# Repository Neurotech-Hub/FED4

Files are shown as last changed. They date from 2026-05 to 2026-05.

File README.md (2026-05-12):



<p align="center">
  FED4 Logo
</p>

<p align="center">
  FED4 Demo
</p>

FED4 (Feeding Experimentation Device) is an open-source device for training mice. The device provides comprehensive control over feeding experiments, environmental monitoring, and data collection. Features:

- Automated pellet dispensing system 
- Three nose-pokes
- Pellet approach sensor
- Multi-colored signal LEDs
- Audio feedback
- Haptic feedback
- Temperature/Humidity monitoring
- Activity monitoring
- Optional Hublink integration for network connectivity

See the Wiki for more information!

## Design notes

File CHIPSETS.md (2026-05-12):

# Specific chipsets used in FED4

| Subsystem | Chip / module | Notes |
|---|---|---|
| Main platform | **ESP32 (ESP32‑S3 family)** | Main MCU (library `architectures=esp32`; code notes ESP32‑S3 specifics) |
| Power / battery | **MAX17048** | LiPo fuel gauge / battery monitor |
| Timekeeping | **DS3231** | Real-time clock (RTC) |
| I/O expansion | **MCP23X17** (MCP23017 family) | GPIO expander (photogates, haptics control, ToF XSHUT, etc.) |
| Environmental sensing | **BME680** | Temperature / humidity / pressure / gas |
| Environmental sensing | **VEML7700** | Ambient light |
| Motion / presence | **STHS34PF80** | Motion (presence) sensor |
| Distance / proximity | **VL53L1X** | Time-of-flight (ToF) distance / proximity |
| Inertial (optional) | **LIS3DH** | 3-axis accelerometer (hardware present; optional in sketches) |
| Magnetic (optional) | **MLX90393** | 3-axis magnetometer (hardware present; optional in sketches) |
| Audio | **MAX98357A** | I2S audio amplifier (speaker output) |
| LEDs | **NeoPixel / WS2812-family** | RGB LEDs (front strip + status pixel) |
| Display | **Sharp Memory Display** | 144×168, SPI, 1-bit monochrome |
| Optional wireless | **Hublink (BLE)** | Radio chipset not specified in this repo |

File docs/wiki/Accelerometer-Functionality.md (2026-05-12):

# FED4 Accelerometer Functionality

The FED4 has a **LIS3DH** accelerometer on the secondary I2C bus (address **0x19**). **It is currently not used** by any built-in FED4 programs; the API is available for custom sketches.

**API**

- **`initializeAccel()`** — init sensor (called from `begin()`). Default: ±2g, 50 Hz, high-resolution (12-bit).
- **`readAccel(x, y, z)`** — read acceleration in **m/s²**, remapped to device axes (x = left/right, y = forward/back, z = up/down).
- **`getAccelEvent(&event)`** — raw chip axes via `sensors_event_t`.
- **`setAccelRange(...)`**, **`setAccelDataRate(...)`**, **`setAccelPerformanceMode(...)`** — configure range (±2/4/8/16 g), rate (1–400 Hz), and mode (low-power / normal / high-res).
- **`accelDataReady()`** — `true` when new data is available.

See [FED4_Accel.cpp](https://github.com/KravitzLabDevices/FED4/blob/main/src/FED4_Accel.cpp). Example: [FED4-Accel-Test](https://github.com/KravitzLabDevices/FED4/tree/main/examples/3_Troubleshooting/HardwareExamples/FED4-Accel-Test).

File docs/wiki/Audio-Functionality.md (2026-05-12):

# FED4 Audio Functionality

The FED4 uses an **I2S-driven speaker** (MAX98357A). Audio is initialized in `begin()`.

**Tones and beeps**

- **`playTone(frequency, duration_ms, amplitude)`** — single tone (e.g. `playTone(500, 200, 0.25)`).
- **`lowBeep()`** — 500 Hz, 200 ms. **`highBeep()`** — 1000 Hz. **`higherBeep()`** — 2000 Hz.
- **`click()`** — short click (quick feedback).
- **`bopBeep()`** — two-tone beep (1000 Hz → 1600 Hz).

**Jingles**

- **`playStartup()`** — startup melody. **`resetJingle()`** — power-cycle jingle. **`menuJingle()`** — menu arpeggio.

**"Super Mario"-style sound effects (tone synthesis)**

- **`marioCoin()`** — coin pickup sound (approx).
- **`marioJump()`** — jump sound (approx).
- **`marioPipe()`** — pipe/travel “bloop” (approx).
- **`marioFireball()`** — fireball shot sound (approx).
- **`marioMushroom()`** — power-up sound (approx).

**Other**

- **`soundSweep(startFreq, endFreq, duration_ms)`** — frequency sweep. **`noise(duration_ms, amplitude)`** — white noise.
- **`silence()`** / **`unsilence()`** — mute audio (persists across reboots). **`enableAmp(bool)`** — amp on/off. **`resetSpeaker()`** — reinit I2S.

See [FED4_Audio.cpp](https://github.com/KravitzLabDevices/FED4/blob/main/src/FED4_Audio.cpp).

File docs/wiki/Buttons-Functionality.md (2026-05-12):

# FED4 Buttons Functionality

The FED4 has **three user buttons** (GPIO **BUTTON_1** = 40, **BUTTON_2** = 39, **BUTTON_3** = 14), arranged bottom / middle / top. They use internal pull-down and can **wake the device** from light sleep. There is **no general-purpose “button pressed” API** for sketches; the library assigns fixed behaviors.

**Default behavior (on wake)**

- **`checkButton1()`** — **Button 1 (bottom):** Hold ~1 s → test pellet dispense (`feed()`), `bopBeep()`.
- **`checkButton2()`** — **Button 2 (middle):** Hold ~1 s → **device reset** (red wipe, `resetJingle()`, `esp_restart()`).
- **`checkButton3()`** — **Button 3 (top):** Hold **500 ms** → **audio toggle** (`silence` / `unsilence`), plus `click()`. Hold **1500 ms** → **menu** (`menu()`), `hapticDoubleBuzz()`.

These are run from **`wakeUp()`** after a **button** wake (not touch). Poll with **`digitalRead(BUTTON_1)`** etc. (HIGH = pressed) if you need raw state elsewhere (e.g. menu, dispense loop).

See [FED4_Buttons.cpp](https://github.com/KravitzLabDevices/FED4/blob/main/src/FED4_Buttons.cpp), [FED4_Pins.h](https://github.com/KravitzLabDevices/FED4/blob/main/src/FED4_Pins.h).

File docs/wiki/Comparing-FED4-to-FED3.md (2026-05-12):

# FED4 vs FED3 (Quick Comparison)

This page summarizes high‑level differences using the **FED4 README** and the **FED3 specifications/wiki**. Where FED4 specs are not published, the table notes “not listed.”

## At a glance

| Category | FED4 | FED3 |
|---|---|---|
| **Core purpose** | Feeding experimentation device; integrated environmental monitoring and data logging | Feeding experimentation device |
| **Nose‑pokes** | Three | Three (per FED3 wiki) |
| **Pellet dispenser** | Updated design; **dispensing is greatly improved vs FED3** | Legacy FED3 dispenser |
| **Wireless / cloud** | Optional **Hublink** (BLE → gateway → hublink.cloud), auto‑configured via `meta.json` | Not listed in FED3 specs/wiki |
| **Screen** | Sharp Memory Display, 144×168 (from FED4 code) | Sharp Memory Display (FED3 wiki) |
| **Battery** | Not listed in FED4 README | 3.7 V 4400 mAh (FED3 wiki) |
| **Weight** | Not listed in FED4 README | 295 g (FED3 wiki) |
| **Dimensions** | Not listed in FED4 README | 135×85×86 mm (FED3 wiki) |
| **Processor** | Not listed in FED4 README | Feather M0 Adalogger (FED3 wiki) |

## FED4 highlights (from FED4 README)

| Area | FED4 highlights |
|---|---|
| **Sensors** | BME680 (temp/humidity/pressure/gas), VEML7700 (ambient light), VL53L1X (ToF), STHS34PF80 (motion), DS3231 RTC, plus LIS3DH accel + MLX90393 magnetometer (hardware present; currently unused in default programs) |
| **Outputs** | Multicolor nose‑poke LEDs, audio, haptic, SD logging |
| **Wireless** | Optional Hublink; enable with `fed.useHublink = true` and it syncs automatically in `run()` |

## FED3 specs (from FED3 wiki)

| Spec | FED3 |
|---|---|
| **Weight** | 295 g |
| **Dimensions** | 135×85×86 mm |
| **Processor** | Feather M0 Adalogger |
| **Screen** | Sharp Memory Display |
| **Battery** | 3.7 V 4400 mAh (~7 days continuous) |
| **Pellets** | 20 mg precision pellets (TestDiet, Bio‑Serv, etc.) |

## Sources

- FED4 README: https://github.com/KravitzLabDevices/FED4  
- FED3 specifications (wiki): https://github.com/KravitzLabDevices/FED3/wiki/FED3-Specifications  
- FED3 library: https://github.com/KravitzLabDevices/FED3_library

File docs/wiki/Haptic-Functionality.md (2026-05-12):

# FED4 Haptic Functionality

The FED4 drives a **haptic motor** via the MCP expander (pin **EXP_HAPTIC**). Used for vibration feedback on pokes, buttons, and events.

**Functions**

- **`hapticBuzz(duration)`** — single buzz (default 100 ms).
- **`hapticDoubleBuzz(duration)`** — two buzzes (default 25 ms each).
- **`hapticTripleBuzz(duration)`** — three buzzes (default 5 ms base; on/off = duration×10).
- **`hapticRumble(duration_ms)`** — low-frequency PWM rumble (default 300 ms, 50 Hz).

Durations are in milliseconds unless noted. See [FED4_Haptic.cpp](https://github.com/KravitzLabDevices/FED4/blob/main/src/FED4_Haptic.cpp).

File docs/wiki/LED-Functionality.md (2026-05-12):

# FED4 LED Functionality

The FED4 has **two LED systems**: a **front strip** of 8 NeoPixels around the nose-pokes, and a **single status NeoPixel**.

**Front strip (poke lights)**

- **`leftLight("red")`**, **`centerLight("green")`**, **`rightLight("blue")`** — light left/center/right poke; optional brightness: `leftLight("red", 100)`.
- **`setStripPixel(i, "green")`** — individual strip LED.
- **`colorWipe("white", 10)`**, **`stripRainbow(50, 1)`** — animations; **`lightsOff()`** — clear strip.

**Status pixel**

- **`redPix(5)`**, **`greenPix(5)`**, **`bluePix(5)`**, **`noPix()`**, etc.

**Colors:** `"red"`, `"green"`, `"blue"`, `"yellow"`, `"purple"`, `"cyan"`, `"orange"`, `"white"`.

See [FED4_LEDs.cpp](https://github.com/KravitzLabDevices/FED4/blob/main/src/FED4_LEDs.cpp).

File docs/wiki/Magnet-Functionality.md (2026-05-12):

# FED4 Magnet (Magnetometer) Functionality

The FED4 has an **MLX90393** magnetometer on the secondary I2C bus (address **0x0C**). **It is currently not used** by any built-in FED4 programs; the API is available for custom sketches.

**API**

- **`initializeMagnet()`** — init sensor (called from `begin()`). Uses **`configureMagnet()`** with default gain (5×).
- **`readMagnetData(x, y, z)`** — read magnetic field (µT) into `float` refs. Returns `true` on success.
- **`getMagnetEvent(&event)`** — raw data via `sensors_event_t`.
- **`setMagnetGain(...)`** / **`getMagnetGain()`** — configure or read gain (e.g. `MLX90393_GAIN_5X`).
- **`configureMagnet(gain)`** — set gain, resolution, oversampling, and filter (default 5× gain).

See [FED4_Magnet.cpp](https://github.com/KravitzLabDevices/FED4/blob/main/src/FED4_Magnet.cpp). Hardware: [Adafruit MLX90393](https://www.adafruit.com/product/4022), [Adafruit library](https://github.com/adafruit/Adafruit_MLX90393_Library).

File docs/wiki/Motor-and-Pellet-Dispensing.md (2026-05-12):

# FED4 Motor and Pellet Dispensing

The FED4 drives a **stepper motor** to rotate a hopper and dispense pellets. The **dispenser is greatly improved over FED3**, with better jam handling, pellet-in-well detection, optional drop sensor, and retrieval/poke logging.

**Motor**

- **Stepper:** 4-phase, 512 steps/rev. Pins **MOTOR_PIN_1–4** (46, 37, 21, 38); **MOTOR_SPEED** = 24. **Battery required** for motor operation.
- **`initializeMotor()`** — configure pins, set speed (called from `begin()`).
- **`releaseMotor()`** — coil pins LOW to save power between moves.
- **`motorTurns`** — counts small steps during dispense; ~**25** ≈ one pellet position, ~**1000** ≈ one hopper rotation. Logged (as `motorTurns/25`) on **PelletTaken** etc.

**Dispensing and feeding**

- **`feed()`** — full sequence: **`initFeeding()`** → **`dispense()`** → **`handlePelletSettling()`** → **`handlePelletInWell()`** → **`finishFeeding()`**.
- **`dispense()`** — steps motor (`stepper.step(-10)`) until **`checkForPellet()`** (well) or **`didPelletDrop()`** (optional drop sensor). Every 25 steps, **`releaseMotor()`** + 1 s delay. **`handleJams()`** runs each iteration.
- **`checkForPellet()`** — pellet in well (photogate **EXP_PHOTOGATE_1**). **`didPelletDrop()`** — pellet dropped (optional **EXP_PHOTOGATE_4**); **`initializeDropSensor()`** probes for drop sensor at init.
- **`handlePelletSettling()`** — wait up to **500 ms** for pellet in well; **`dispenseError`** = true if not seen. Then **`handlePelletInWell()`** polls until pellet taken or **20 s** timeout (retrieval time, pokes, etc.).

**Jam handling**

- **`minorJamClear()`** — 200 steps, 1 s pause. **`majorJamClear()`** — 1000 steps. **`vibrateJamClear()`** — short back‑and‑forth wobble. Used at **100** and **200** motorTurns during dispense.
- **`jammed()`** — after **2000** motorTurns without dispense: **DispenseError** on display, **`logData("DispenseError")`**, motor off, then sleep loop; **Button 2** reset to recover.

**Relevant members:** **`pelletCount`**, **`pelletPresent`**, **`pelletDropped`**, **`pelletReady`**, **`dispenseError`**, **`retrievalTime`**, **`pelletDropTime`**, **`pelletWellTime`**, **`blockPelletCount`** / **`blockPokeCount`**.

See [FED4_Motor.cpp](https://github.com/KravitzLabDevices/FED4/blob/main/src/FED4_Motor.cpp), [FED4_Feed.cpp](https://github.com/KravitzLabDevices/FED4/blob/main/src/FED4_Feed.cpp), [FED4_Pins.h](https://github.com/KravitzLabDevices/FED4/blob/main/src/FED4_Pins.h).

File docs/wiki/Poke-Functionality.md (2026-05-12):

# FED4 Poke (Nose-Poke) Functionality

The FED4 has **three nose-pokes** (left, center, right) detected by **ESP32 capacitive touch** pads (see [FED4_Pins.h](https://github.com/KravitzLabDevices/FED4/blob/main/src/FED4_Pins.h)). **Touch wakes** the device from light sleep. After `run()` returns, check `leftTouch`, `centerTouch`, or `rightTouch`; then `logData("Left")` (etc.), `feed()`, and light/sound as needed. Counters: `leftCount`, `centerCount`, `rightCount`; hold duration: `pokeDuration` (ms). Calibration is automatic at startup and periodically; sensitivity can differ on USB vs battery.

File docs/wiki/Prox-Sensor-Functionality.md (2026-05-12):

# FED4 Prox (Proximity) Sensor Functionality

The FED4 uses a **VL53L1X time-of-flight (ToF)** distance sensor on the primary I2C bus (XSHUT on MCP pin 1). Measures approach distance to the nose port.

**API**

- **`initializeToF()`** — init ToF sensor (called from `begin()`). Returns `true` on success.
- **`prox()`** — take a single distance reading. Returns **distance in mm** (0–150), or **`-1`** on error/timeout.

**Details**

- Raw reading is offset by a **20 mm calibration** (configurable in code). Values &lt; 0 are clamped to 0; &gt; 150 mm are capped at 150.
- Used for approach detection (e.g. Pavlovian_Prox) and to exercise the primary I2C bus before secondary use (e.g. in `pollSensors()`).

See [FED4_Prox.cpp](https://github.com/KravitzLabDevices/FED4/blob/main/src/FED4_Prox.cpp). Hardware: [SparkFun VL53L1X](https://www.sparkfun.com/products/14722), [SparkFun Arduino library](https://github.com/sparkfun/SparkFun_VL53L1X_Arduino_Library).

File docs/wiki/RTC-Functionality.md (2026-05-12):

# FED4 RTC (Real-Time Clock) Functionality

The FED4 uses a **DS3231 RTC** on the secondary I2C bus to keep accurate time across power cycles. Time is used for **logs, display, and scheduling**.

**Initialization and auto-update**

- **`initializeRTC()`** — starts the DS3231 and loads time into the internal clock. On **new compilation**, the RTC is updated to the build time.
- **Compilation detection** — a stored compile timestamp in Preferences triggers **`updateRTC()`** only when firmware changes.

**Key API**

- **`now()`** — returns `DateTime` from the RTC.
- **`updateTime()`** — updates `currentHour`, `currentMinute`, `currentSecond`, `unixtime`.
- **`adjustRTC(timestamp)`** — sets RTC from a Unix timestamp (used by Hublink time sync).

**Logging**

- **`ElapsedSeconds`** in the SD log is **millis-based**, rounded to **0.001 s** (1 ms resolution).

**Manual set**

- **`menuRTC()`** — interactive RTC setting in the FED4 menu.

See [FED4_RTC.cpp](https://github.com/KravitzLabDevices/FED4/blob/main/src/FED4_RTC.cpp), [RTClib](https://github.com/adafruit/RTClib).

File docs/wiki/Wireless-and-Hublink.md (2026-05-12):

# FED4 Wireless Capabilities and Hublink

The FED4 supports **wireless connectivity** via **Hublink**, which uses **BLE** to connect nodes (FED4) to a gateway, and the gateway to **[hublink.cloud](https://hublink.cloud)** for time sync, file uploads, and alerts. FED4 is **automatically configured for hublink.cloud** through the **`meta.json`** file on the SD card—no Hublink-specific code is required beyond enabling it.

**Automatic configuration (meta.json)**

- The **`meta.json`** schema is **compatible with hublink.cloud**. A **`hublink`** section configures BLE advertising and upload behavior:
  - **`advertise`** — BLE advertising name (e.g. `"FED4"`).
  - **`advertise_every`** — seconds between advertising periods (e.g. 300).
  - **`advertise_for`** — duration of each advertising period in seconds (e.g. 30).
  - **`upload_path`**, **`append_path`** — where files go in cloud storage (e.g. `/FED`, `subject:id`).
  - **`disable`** — set `true` to turn Hublink off.
- **`subject`**, **`device`**, etc. in **`meta.json`** are used for metadata and paths. The same file drives both FED4 metadata and Hublink; **one config, automatically applied** when Hublink is enabled.

**Enabling Hublink**

- Set **`fed.useHublink = true`** before **`fed.begin(...)`**. **`begin()`** then calls **`initializeHublink()`** (reads **`meta.json`**, starts Hublink). **`run()`** calls **`syncHublink()`** before sleep—**sync is automatic** each wake cycle.
- **`initializeHublink()`** — init Hublink (uses **SD_CS** pin); registers **`onHublinkTimestampReceived`** for RTC updates.
- **`syncHublink()`** — sets battery level, low-battery alerts, and runs **`hublink.sync()`** (advertise/connect, upload files, receive time).

**What runs automatically**

- **RTC time sync** — timestamps from Hublink update the RTC via **`adjustRTC()`**.
- **Low-battery alerts** — battery under 20% triggers **`hublink.setAlert("Low Battery!")`** before sync.
- **File uploads** — log files (and **`meta.json`**) are uploaded according to **`upload_path`** / **`append_path`** when the gateway is in range.

**Optional exclusion**

- **`#define FED4_EXCLUDE_HUBLINK`** before **`#include <FED4.h>`** removes Hublink from the build to save code size.

**Requirements:** Hublink library, SD card with **`meta.json`**, gateway in range for BLE, and internet for the gateway → hublink.cloud.

See [FED4_Hublink.cpp](https://github.com/KravitzLabDevices/FED4/blob/main/src/FED4_Hublink.cpp), [Hublink examples](https://github.com/KravitzLabDevices/FED4/tree/main/examples/4_Hublink), [meta.json example](https://github.com/KravitzLabDevices/FED4/blob/main/extras/meta.json_examples/meta.json). Full config and cloud usage: **[hublink.cloud/docs](https://hublink.cloud/docs)**.

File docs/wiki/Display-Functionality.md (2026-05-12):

# FED4 Display (Screen) Functionality

The FED4 uses a **Sharp Memory Display** (SPI, **DISPLAY_CS** = 17), **144×168** pixels, 1-bit (black/white). The FED4 class extends **Adafruit_GFX**, so you can use standard GFX calls (`drawPixel`, `fillRect`, `print`, `drawLine`, etc.) plus FED4-specific helpers.

**Initialization and refresh**

- **`initializeDisplay()`** — init display, allocate buffer, clear (called from `begin()`).
- **`updateDisplay()`** — redraw status (task, mouse ID, env, battery, SD, counters, indicators, date/time). Called from `run()` and elsewhere.
- **`refresh()`** — push the backing buffer to the display. Call after drawing.
- **`clearDisplay()`** — clear buffer (white) and refresh.

**Status helpers (used by `updateDisplay`)**

- **`displayTask()`**, **`displayMouseId()`**, **`displayEnvironmental()`**, **`displayBattery()`**, **`displaySDCardStatus()`**, **`displayCounters()`**, **`displayIndicators()`**, **`displayDateTime()`** — status layout.
- **`displayActivityMonitor()`** / **`displayActivityCounters()`** — when program is ActivityMonitor.
- **`displayInitStatus(msg)`** — show init message during `begin()`.
- **`displayLowBatteryWarning()`** — low-battery full-screen message.

**Constants:** `DISPLAY_WIDTH` = 144, `DISPLAY_HEIGHT` = 168; **`DISPLAY_BLACK`**, **`DISPLAY_WHITE`**, **`DISPLAY_INVERSE`**, **`DISPLAY_NORMAL`**.

See [FED4_Display.cpp](https://github.com/KravitzLabDevices/FED4/blob/main/src/FED4_Display.cpp), [FED4.h](https://github.com/KravitzLabDevices/FED4/blob/main/src/FED4.h). [Adafruit Sharp Memory Display](https://learn.adafruit.com/adafruit-sharp-memory-display-breakout), [Adafruit_GFX](https://github.com/adafruit/Adafruit-GFX-Library).

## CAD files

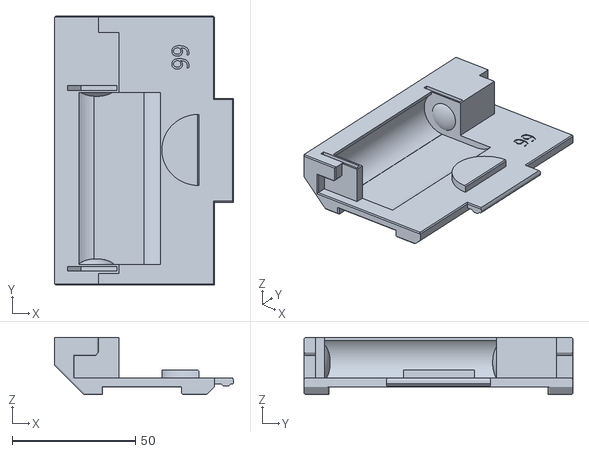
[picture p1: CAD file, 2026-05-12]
extras/3D_designs/FED4_010126_Base_chamfer.stl
72.7 x 109.1 x 23.2

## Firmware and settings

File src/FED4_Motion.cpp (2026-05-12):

#include "FED4.h"

bool FED4::initializeMotion()
{
    // Check if motion sensor should be used
    if (!useMotionSensor) {
        motionSensorInitialized = false;
        motionPercentage = NAN;
        return true; // Return true to indicate "successful" initialization (skipped)
    }
    
    // Reset flag at start of initialization
    motionSensorInitialized = false;
    
    // Test I2C connectivity
#if FED4_BOARD_VERSION == 163
    Wire.beginTransmission(0x5A); // STHS34PF80 default address
    byte error = Wire.endTransmission();
#else
    I2C_2.beginTransmission(0x5A); // STHS34PF80 default address
    byte error = I2C_2.endTransmission();
#endif
    
    if (error != 0) {
        return false;
    }
    
    // Initialize with Adafruit library
#if FED4_BOARD_VERSION == 163
    if (!motionSensor.begin(0x5A, &Wire)) {
#else
    if (!motionSensor.begin(0x5A, &I2C_2)) {
#endif
        return false;
    }
    
    // Set low-pass filter 
    if (!motionSensor.setMotionLowPassFilter(STHS34PF80_LPF_ODR_DIV_50)) {
        return false;
    }
    
    // Set sensitivity to high but not maximum (can cause instability)
    // Range: -128 (ultra sensitive) to 127 (minimum sensitivity)
    if (!motionSensor.setSensitivity(-64)) {
        return false;
    }
    
    // // Use moderate averaging for better stability (default is 32)
    // // Using 8 for good balance between speed and stability
    // if (!motionSensor.setObjAveraging(STHS34PF80_AVG_TMOS_8)) {
    //     return false;
    // }
    
    // Set to 30Hz - maximum rate for motion detection
    // Motion detection REQUIRES continuous operation to maintain baseline
    if (!motionSensor.setOutputDataRate(STHS34PF80_ODR_30_HZ)) {
        return false;
    }

    // Verify sensor is working by reading temperature
    int16_t motionValue1 = motionSensor.readMotion();
    bool motionFlag1 = motionSensor.isMotion();
    
    Serial.println("Motion sensor initialized at 30Hz!");

    // Set flag to prevent unnecessary reinitialization
    motionSensorInitialized = true;
    
    return true;
}

bool FED4::motion()
{
    // Check if motion sensor should be used
    if (!useMotionSensor) {
        return false; // Return false if sensor is disabled
    }
    
    // We use the STHS34PF80 sensor to check for motion in two ways:
    // 1. By checking the internal motion flag from the sensor's algorithm
    // 2. By checking the raw motion value and comparing it to a threshold
    // if either check is true, we return true
   
    // Note: pollCount is incremented in pollSensors() before calling motion()
    
    // Get current time
    DateTime now = rtc.now();
    
    // Read motion raw  motion and internal motion flag values
    int16_t motionValue1 = motionSensor.readMotion();
    bool motionFlag1 = motionSensor.isMotion();
   
    // Print current time and motion values
    Serial.printf("%04d-%02d-%02d %02d:%02d:%02d - ", 
        now.year(), now.month(), now.day(),
        now.hour(), now.minute(), now.second());
    Serial.print("Motion flag: ");
    Serial.print(motionFlag1 ? "TRUE" : "FALSE");
    Serial.print(", Motion raw: ");
    Serial.print(motionValue1);

    // Check for motion using flag OR raw value threshold
    if (motionFlag1 || abs(motionValue1) > 50) {
        // Wait for new data at 30Hz (~33ms per sample)
        delay(35);

        // Second check to confirm
        int16_t motionValue2 = motionSensor.readMotion();
        bool motionFlag2 = motionSensor.isMotion();

        // If either check is true, we return true
        if (motionFlag2 || abs(motionValue2) > 50) {
            motionCount++;
            
            // Update motion percentage after incrementing motionCount (guard against division by zero)
            motionPercentage = (pollCount > 0) ? (float)motionCount / pollCount * 100.0 : 0.0;
            
            Serial.print(", MOTION DETECTED! - ");
            Serial.print(motionPercentage, 2);
            Serial.print("% (");
            Serial.print(motionCount);
            Serial.print("/");
            Serial.print(pollCount);
            Serial.println(")");
            
            return true;
        }
    }
    
    // Update motion percentage even when no motion detected (guard against division by zero)
    motionPercentage = (pollCount > 0) ? (float)motionCount / pollCount * 100.0 : 0.0;
    
    Serial.print(" - ");
    Serial.print(motionPercentage, 2);
    Serial.print("% (");
    Serial.print(motionCount);
    Serial.print("/");
    Serial.print(pollCount);
    Serial.println(")");
    
    return false;
}

// Reset motion tracking counters (call after logging data)
void FED4::resetMotionCounters()
{
    motionCount = 0;
    pollCount = 0;
    motionPercentage = 0.0;
} 

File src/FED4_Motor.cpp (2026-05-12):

#include "FED4.h"
// NOTE: YOU NEED A BATTERY PLUGGED IN FOR THE MOTOR TO RUN.

bool FED4::initializeMotor()
{
    pinMode(MOTOR_PIN_1, OUTPUT);
    pinMode(MOTOR_PIN_2, OUTPUT);
    pinMode(MOTOR_PIN_3, OUTPUT);
    pinMode(MOTOR_PIN_4, OUTPUT);
    stepper.setSpeed(MOTOR_SPEED);
    return true;
}

void FED4::releaseMotor()
{
    digitalWrite(MOTOR_PIN_1, LOW);
    digitalWrite(MOTOR_PIN_2, LOW);
    digitalWrite(MOTOR_PIN_3, LOW);
    digitalWrite(MOTOR_PIN_4, LOW);
}

void FED4::minorJamClear()
{
    Serial.println("MinorJam");
    stepper.step(200);
    delay(1000);
}

void FED4::majorJamClear()
{ // make this function also monitor the pellet well
    Serial.println("MajorJam");
    stepper.step(1000);
    delay(1000);
}

void FED4::vibrateJamClear()
{ // make this function also monitor the pellet well
    Serial.println("VibrateJam");
    for (int i = 0; i < 35; i++)
    {
        stepper.step(10);
        delay(10);
        stepper.step(-20);
        delay(10);
    }
}

void FED4::jammed(){
  fillRect (0, 0, 144, 17, DISPLAY_BLACK);
  
  setFont(&Org_01);
  setTextSize(2);
  setTextColor(DISPLAY_WHITE);

  setCursor(0, 9);
  print("DISPENSE ERR"); 
  refresh();
  releaseMotor();
  logData("DispenseError");
  //turn lEDS off
  lightsOff();
  noPix();

  while(1) {
    // Infinite loop to hang the program
    //LDO2_OFF();  // For now leave this On until we get new boards

    enableAmp(false); 
    syncHublink(); // Sync with Hublink before sleep
    // put FED4 to sleep with timer wakeup for sensor polling
    esp_sleep_enable_timer_wakeup(10 * 1000000); // Wake up every 10 seconds (in microseconds)
    esp_light_sleep_start();
    LDO3_ON();
//    LDO2_ON();
    enableAmp(true);
    // Reinitialize I2C buses for sensor polling
    Wire.begin();
    I2C_2.begin(SDA_2, SCL_2);
    delay(1);

    // Poll sensors every wakeup (pollSensors checks internally if enough time has passed)
    if (program == "ActivityMonitor") {
      pollSensors(1);  // 1 minute interval for ActivityMonitor
    } else {
      pollSensors(10);  // 10 minute interval for other programs
    }
    checkButton2(); //check this button for resetting the device
    delay(100);
  }
}

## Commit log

2026-03-30 I2C Scanning Troubleshooting
2026-04-01 For ToF sensor
2026-05-12 v1.6.2 and v1.6.3 version switching at compile time.
